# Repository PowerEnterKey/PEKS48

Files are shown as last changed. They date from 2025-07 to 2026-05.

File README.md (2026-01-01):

# PEKS48ビルドガイド
自作キーボードキットPEKS48のビルドガイドです。<br>
はんだ付け済み、ケース付き、ファームウェア書き込み済みですので、
ネジを締めて頂くだけでお使い頂けます。

## キット内容

| 名称 | 数  |　補足 |
| --- | --- | --- |
| メイン基板 | 2 |マイコンなど実装済み |
| トッププレート | 2 | |
| ケース(ボトム) | 1 | |
| ケース(トップ) | 1 | |
| Li-Poバッテリ | 2 | |
| ガスケット用フォーム |  -  |ケース及び基板の必要個所に取付済み |
| スイッチ取付面静音フォーム| 48 | |
| M2ネジ | 12 | |
| ゴム足 | 4 | |
| 給電ドッグ | 1 |無線給電機能付きの場合 |

※2025/12/31販売分まではスイッチ取付面静音フォームは取り付け済みで送付していましたが、<br>
　取り付け済みの状態だとスイッチの指す向きが分かりにくいことやフォーム自体がChoc V2適合品ではないことから<br>
　2025/12/31販売分から取り付けずに配布することにしました。<br>
　フォームを使用することで音は良くなるので取り付けを推奨しています。<br>
　取り付け向き等は以降の画像を参照ください。<br>
 
## キット以外に必要なもの

| 名称 | 数  |　補足 |
| --- | --- | --- |
| キースイッチ | 48  |choc v2互換　　|

## 組み立て手順
以下の状態で郵送されます（右手用）。<br>
キーキャップはただ置かれている状態です。<br>
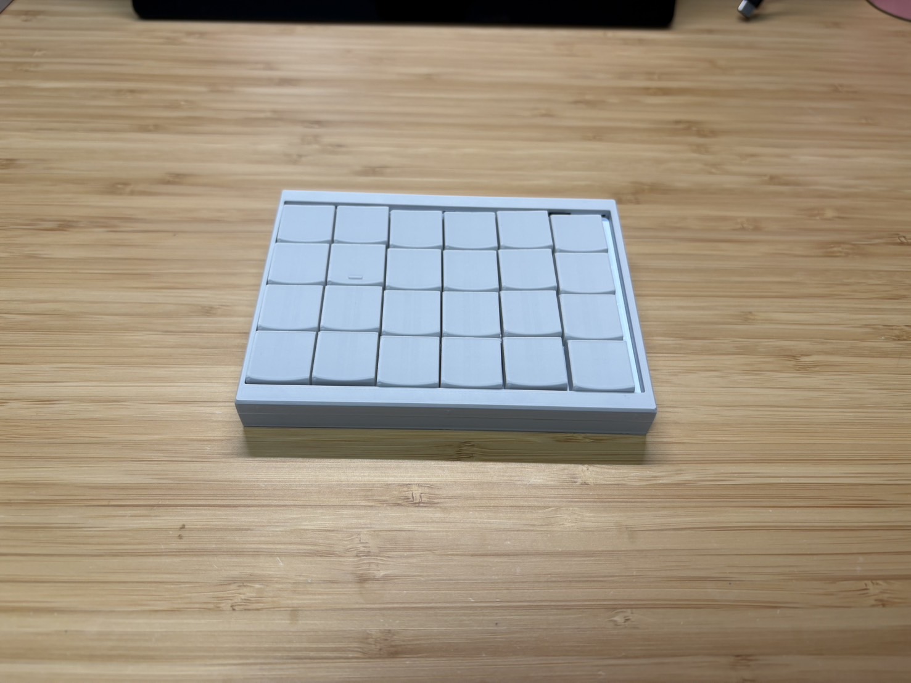
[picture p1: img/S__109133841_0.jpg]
<br>

キーキャップをとると右用か左用かが書かれています。<br>
PEKS48はハードウェアとしては右も左も完全に同じものです。ファームウェアのみ異なります。<br>
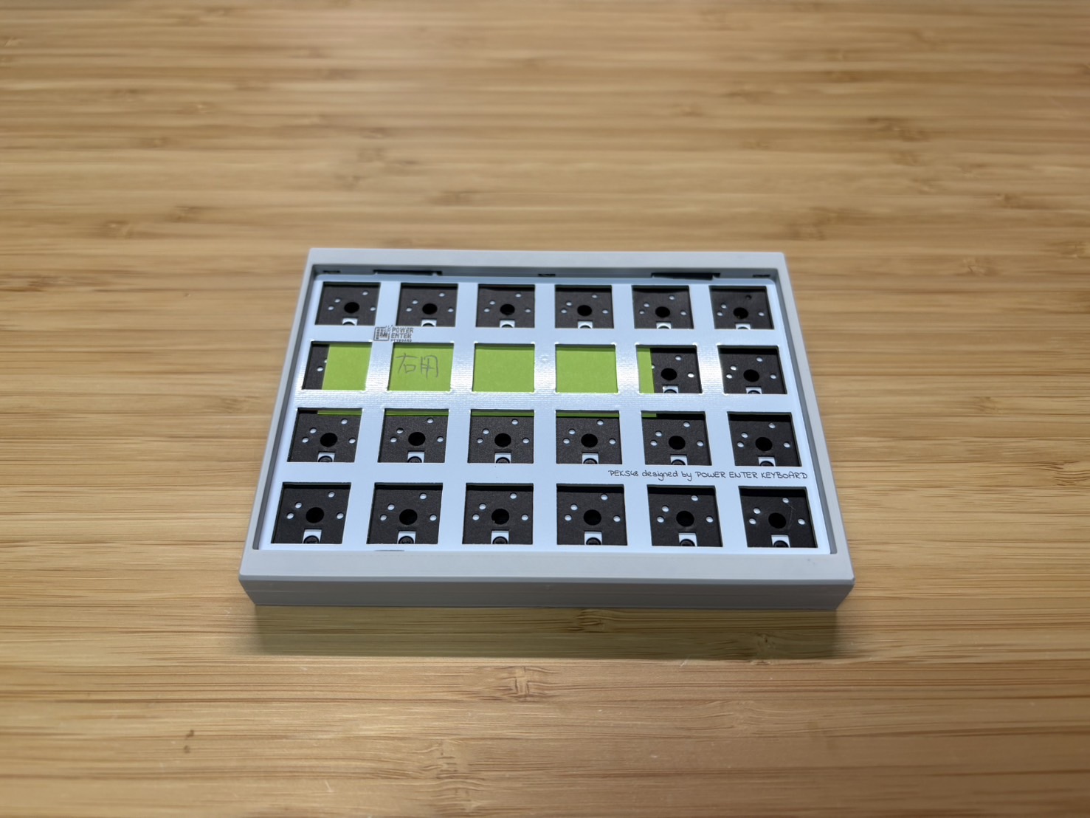
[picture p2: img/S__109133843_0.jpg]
<br>

裏返すと6か所にネジがあるので外します。<br>
(裏面には直径6mm厚さ2.5mmの磁石を入れることが出来る穴があるのでご自由に使用ください。<br>
　※2025/12/31販売分から磁石を入れる穴がケース内部になりました。外側から磁石が見えなくなってすっきりしました。)<br>
ネジを外すとケース(トップ) が外せます。<br>
右の図はケース(トップ) を外した状態です。<br>
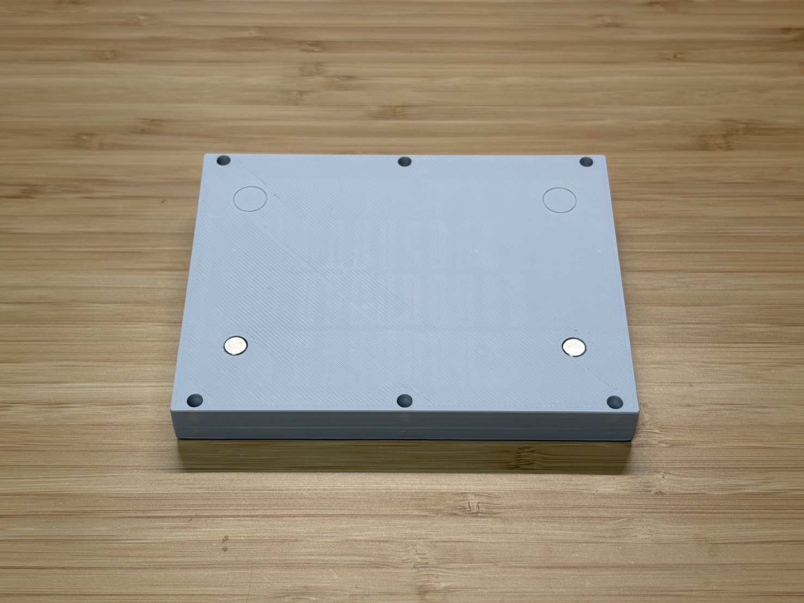
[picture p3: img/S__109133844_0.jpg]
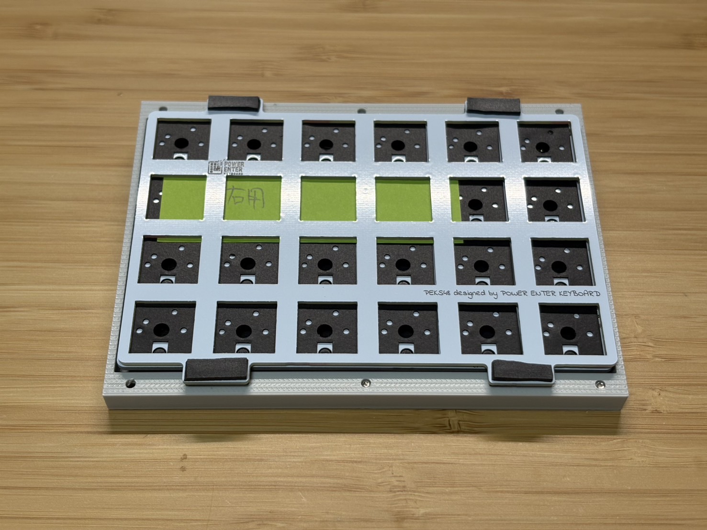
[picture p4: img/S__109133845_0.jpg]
<br>

次に、メイン基板の下側にバッテリが入っていますので、メイン基板と接続します。<br>
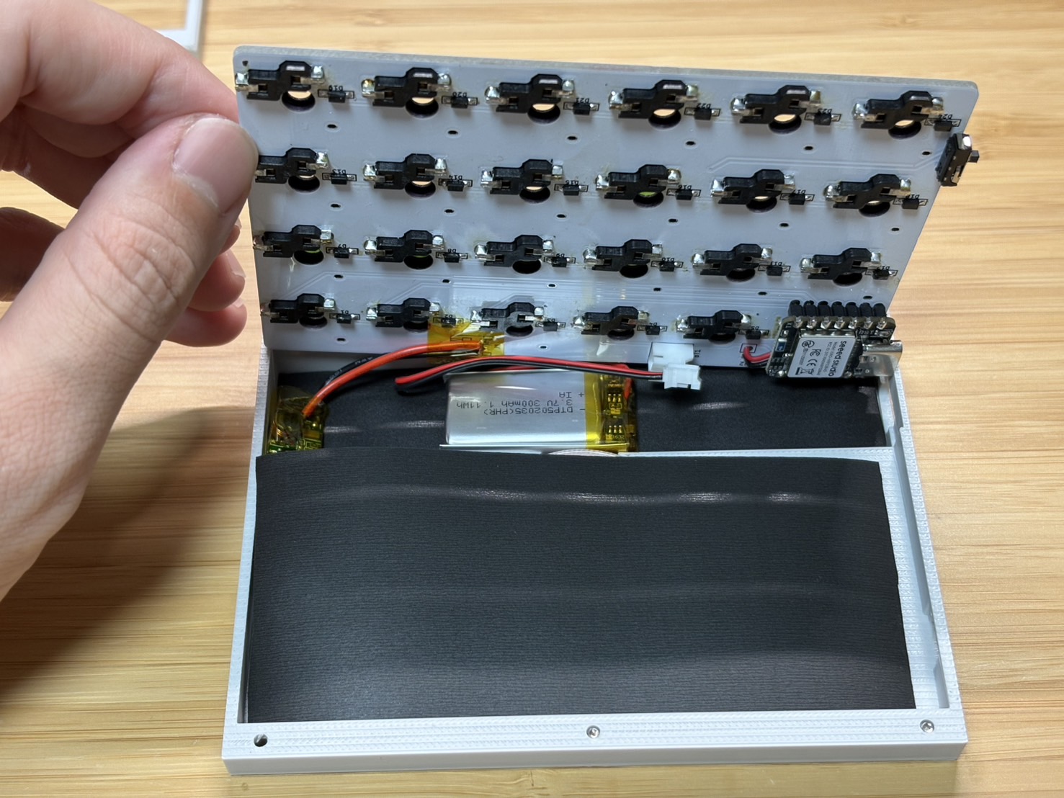
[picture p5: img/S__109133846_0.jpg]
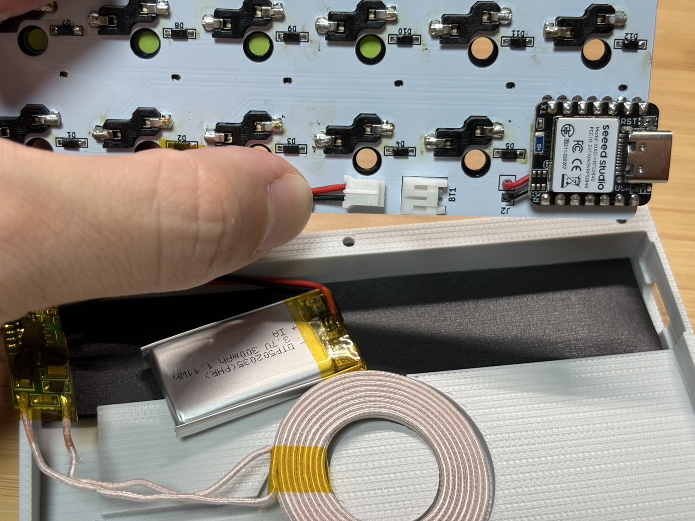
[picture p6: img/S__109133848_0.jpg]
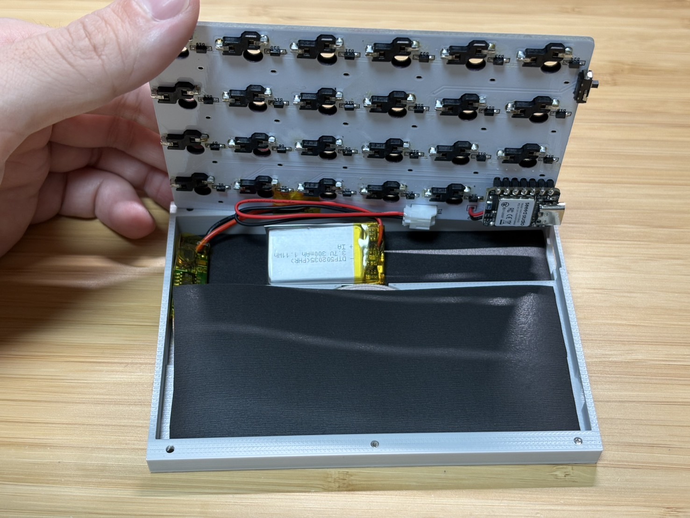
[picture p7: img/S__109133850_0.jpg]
<br>

バッテリがコネクタや無線給電用子基板と干渉しないように配置して、メイン基板をケースに収めます。<br>
※※その際、以下のようにケーブルをケースと基板の間に挟まないように注意してください。※※<br>
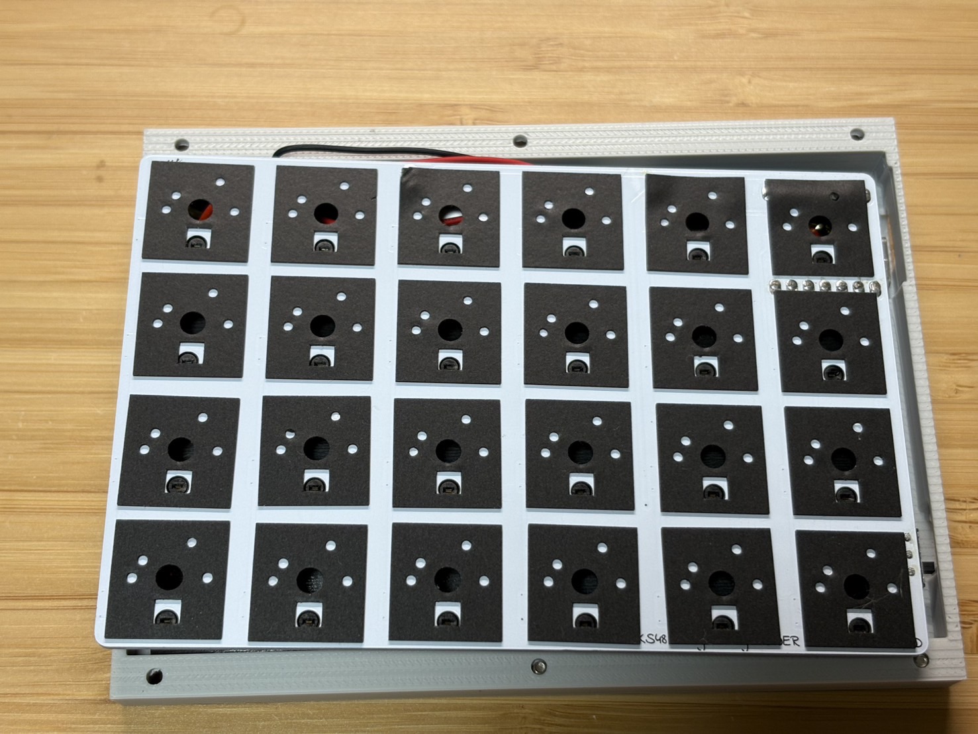
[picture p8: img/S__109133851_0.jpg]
<br>

次に、トッププレートにスイッチをはめていきます。<br>
スイッチはピンがある方が南側にくる向きではめてください。<br>
四隅をはめたらトッププレートごとスイッチを基板に挿します。<br>
そうする事で残りのキースイッチが挿しやすくなります。<br>
トッププレートはそこまで強度がないので注意して扱ってください。<br>
本キーボードは打鍵感向上の為にすでにスイッチ用フォームが基板に貼ってあります。<br>
(※2025/12/31販売分から取り付けずに配布。)<br>
Choc V2用のフォームではないですがこのまま挿して（フォームを貫通させて）問題ないです。<br>
この時点でキーキャップまではめてもよいです。<br>
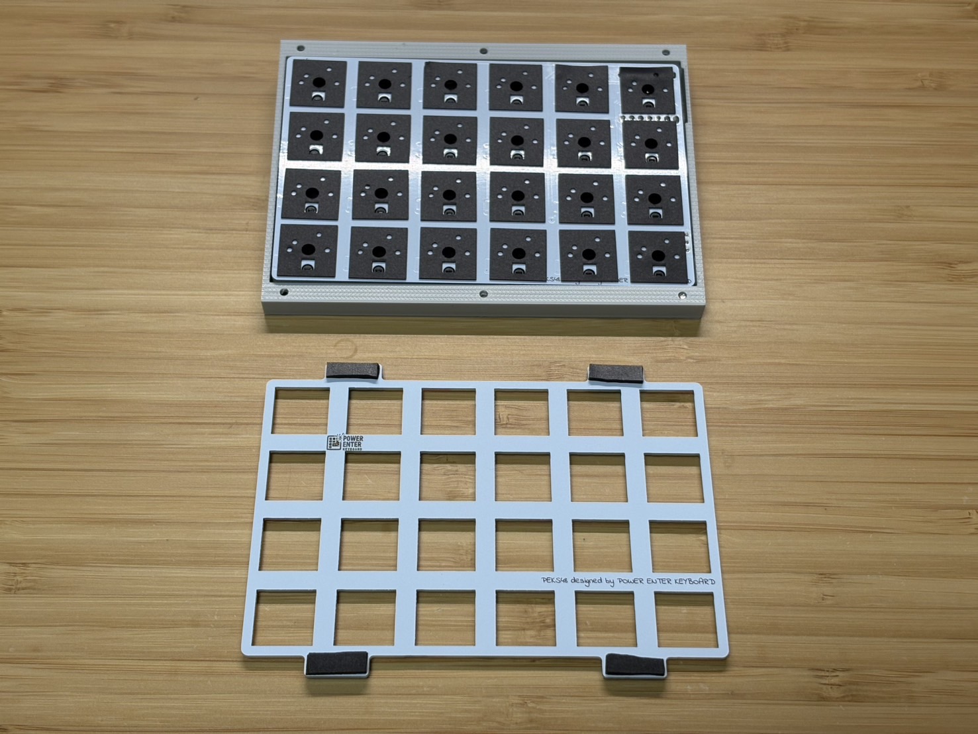
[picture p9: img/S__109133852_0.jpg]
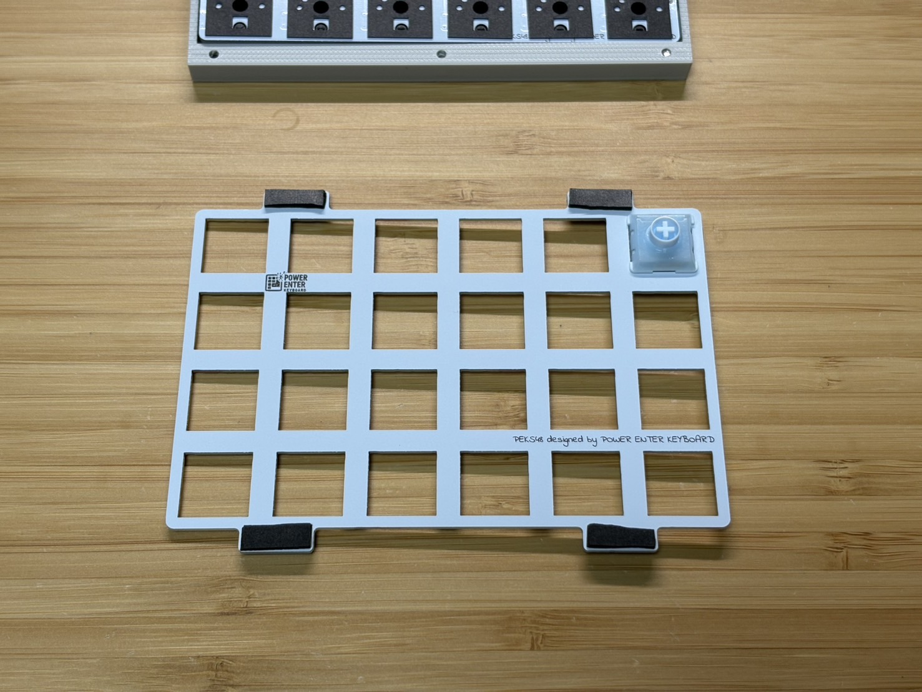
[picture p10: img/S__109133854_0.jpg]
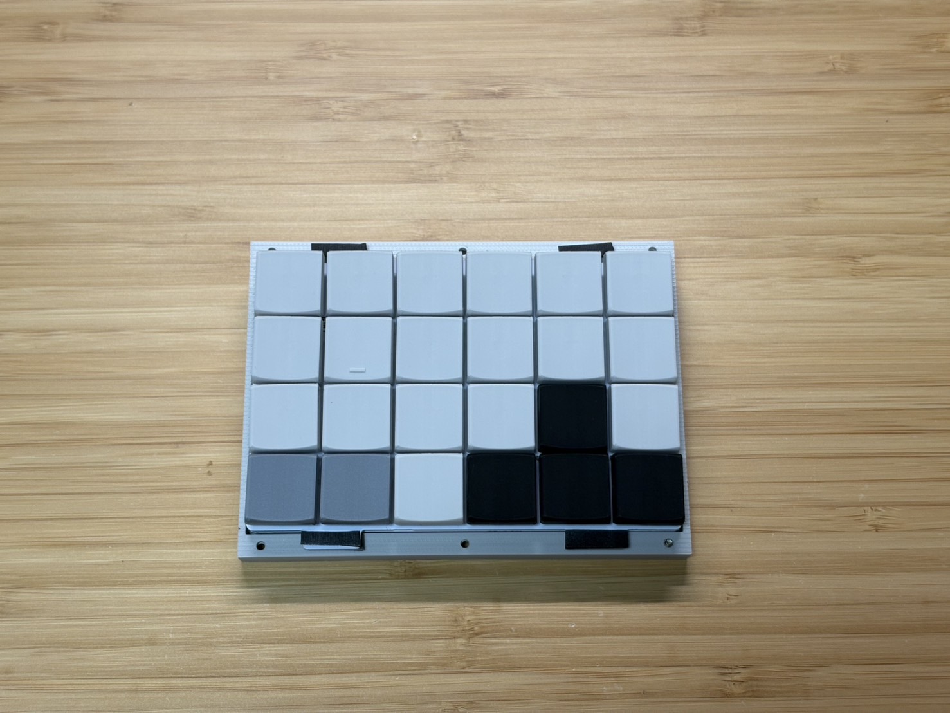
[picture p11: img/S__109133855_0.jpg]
<br>

ボトムケース、メイン基板＋トッププレート、トップケースの順に重ねてねじを締めます。<br>
トップケースにはインサートナットが埋め込まれています。<br>
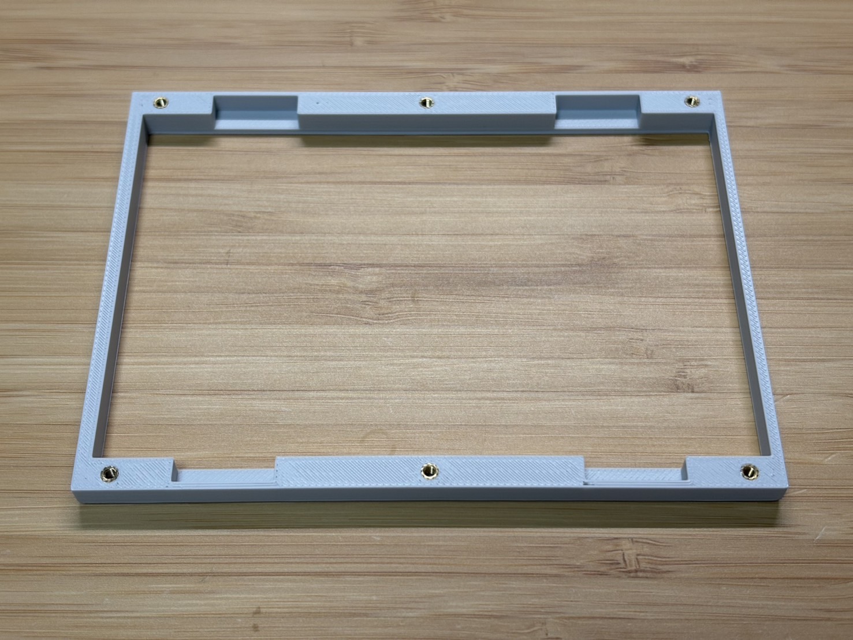
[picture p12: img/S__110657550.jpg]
<br>
また、ケース(トップ) は左右対称ではなく、右側が少し太くなっています。<br>
分かりにくいですが、若干太い方を右側にしてください。

最後に、ケース（トップ）を基板に被せて、開けた時のようにボトム側から6か所のネジを締めれば完成です。<br>
ケース裏面にゴム足を張る丸いマークがついています。ここに付属のゴム足をはると給電ドックとぴったりはまります。<br>
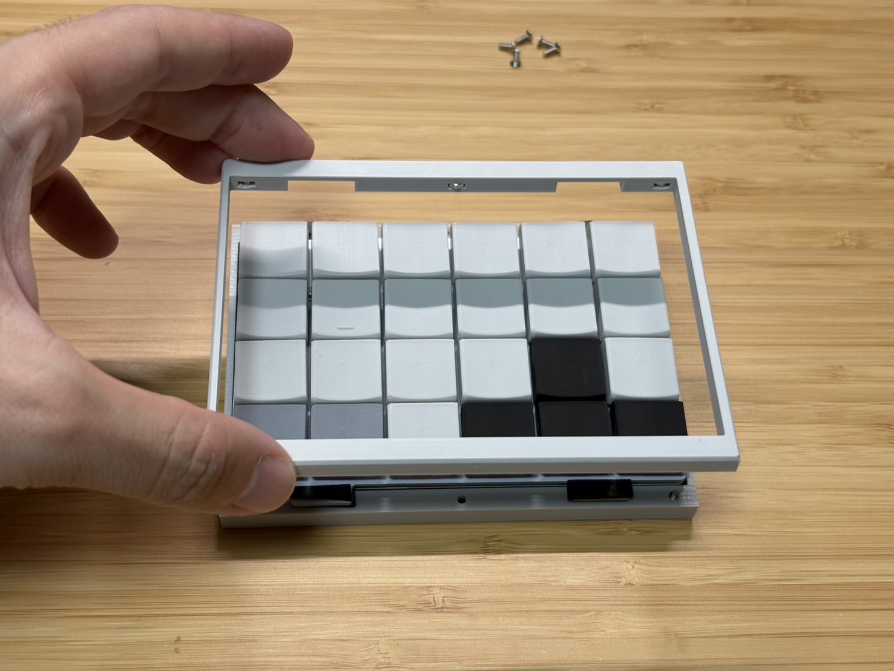
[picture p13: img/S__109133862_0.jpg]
<br>

※2025/12/31販売分から滑り止めがグリップラスという製品になりました。<br>
それに合わせてケース裏の目印も六角形になりました。<br>
上部2つのみに付けるとケースを重ねた時に滑り止め同士が干渉しにくいです。<br>
2つで滑り止め効果が弱いと感じる場合は目印通り4か所に付けてください。<br>
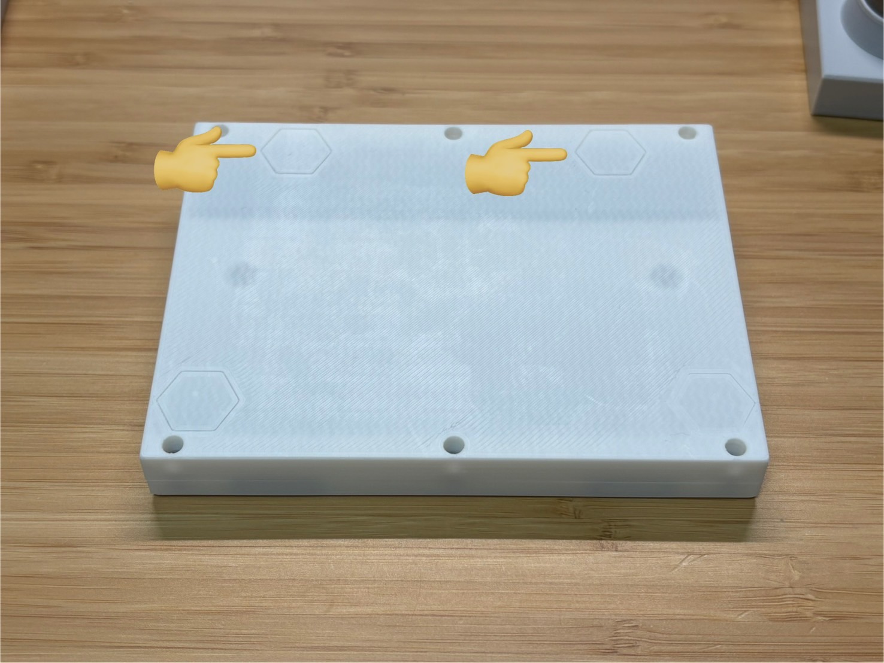
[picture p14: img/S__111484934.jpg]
<br>

完成です！！<br>
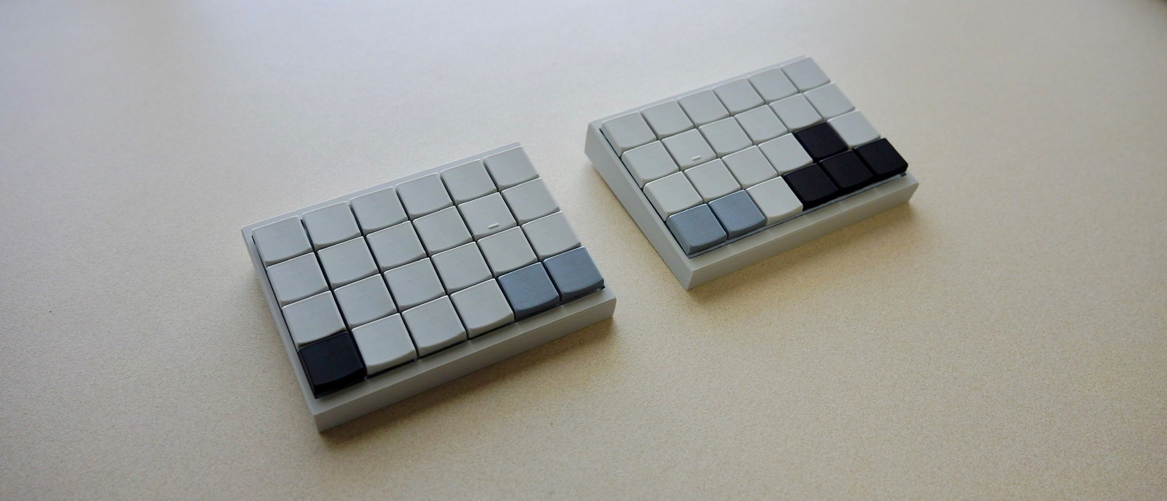
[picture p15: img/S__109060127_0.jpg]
<br>

## 無線給電について(※無線給電対応モデルのみ)
キーボードの裏にはマグネットが付いています。<br>
（下部3つのネジ穴の上にある2つの丸がマグネットが入る穴です）<br>
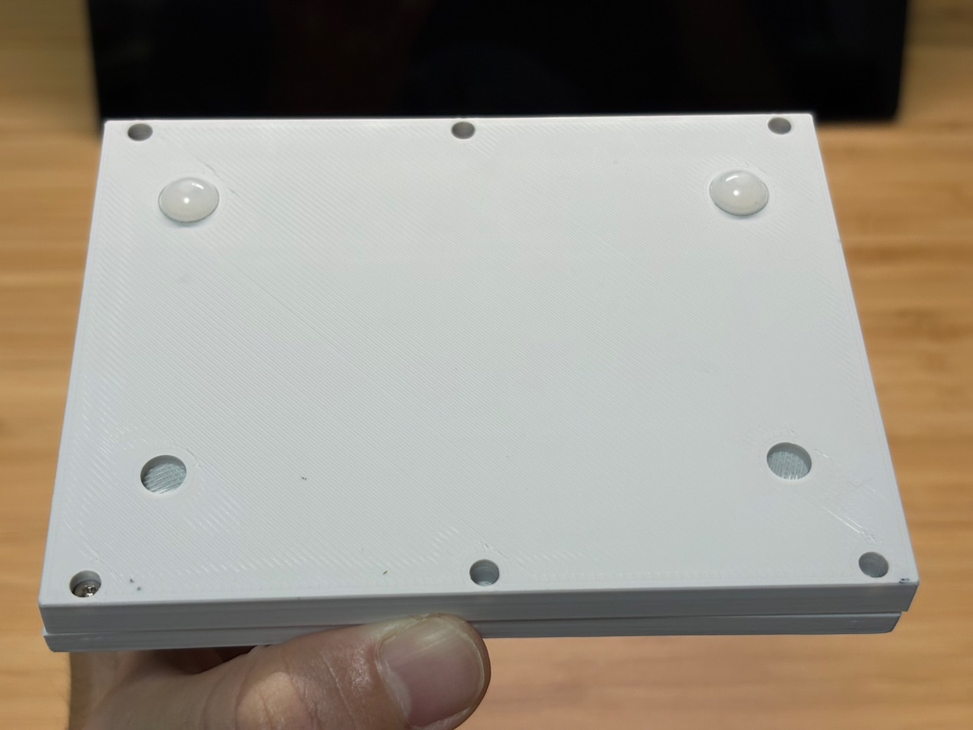
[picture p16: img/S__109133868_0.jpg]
<br>
無線給電したい際は、付属の無線給電ドッグのマグネットとキーボードのマグネットの位置を合わせると給電が始まります。<br>
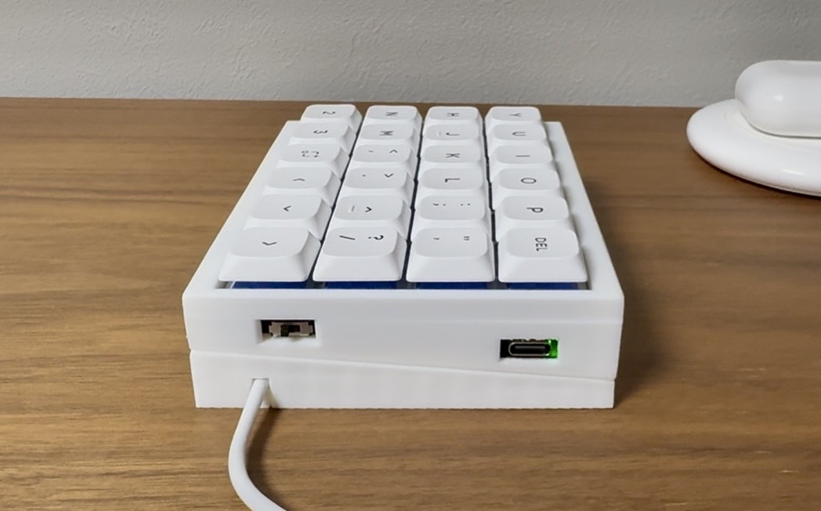
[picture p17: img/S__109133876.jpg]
<br>
PEKS48の無線給電機能は付属の給電ドックのみに対応しています。<br>
同様に付属の給電ドックはPEKS48のみに対応しています。<br>
対応しない機器での充電は避けてください。<br>

## 電源スイッチ
キーボード横に電源用スイッチがあります。（下記写真の左側の四角い穴）<br>
キーボードに向かって奥側（下記写真の右方向）が「ON」（バッテリからの給電許可）です。<br>
無線給電時はスイッチが「ON」でも「OFF」でも起動します。<br>
バッテリに充電したいときは「ON」にしてから給電ドックもしくはUSBを接続して充電してください。<br>
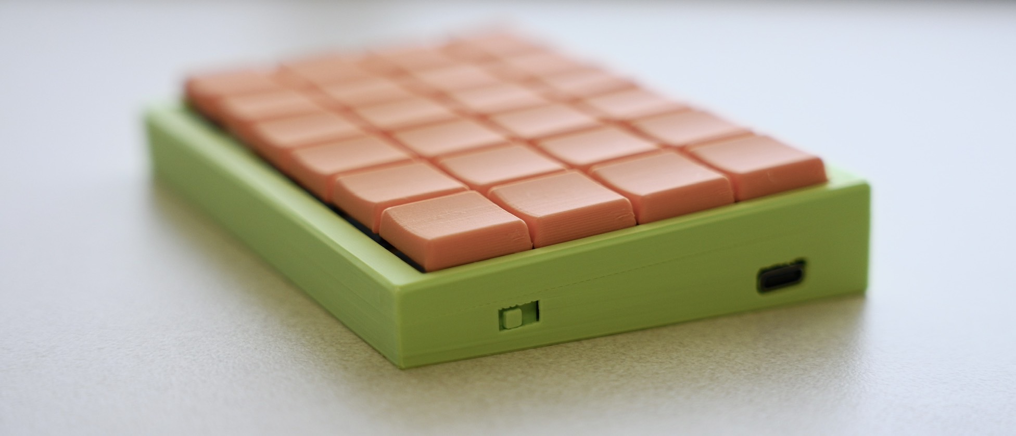
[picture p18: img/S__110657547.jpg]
<br>

## 初期キー配置
初期のキー配置は以下のようになっています。<br>
(日本語キーボードとして使用しているのでkeymap Editor上では一部エラーとして表示されてしまいます)<br>
詳細なキー配置は下記レポジトリのpeks48.keymapをご確認ください。<br>
[https://github.com/PowerEnterKey/zmk-PEKS48<br>](https://github.com/PowerEnterKey/zmk-PEKS48/blob/main/boards/shields/peks48/peks48.keymap)
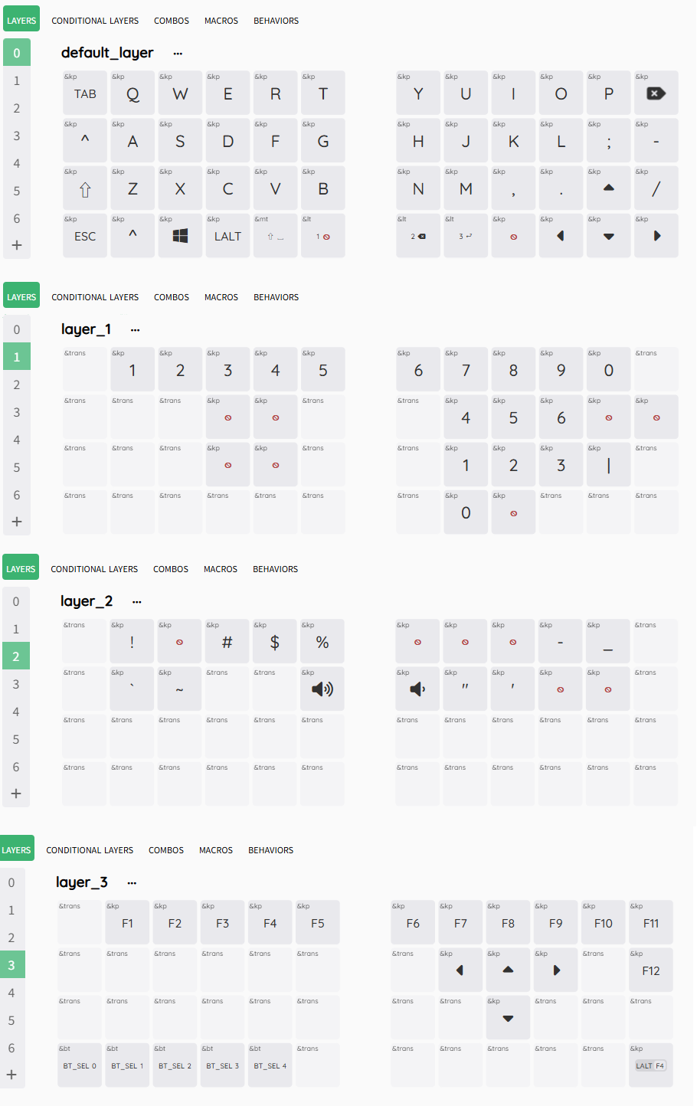
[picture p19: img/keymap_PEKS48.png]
<br>

PEKS48はKeymap Editorに対応しています。<br>
キーマップを変更したい場合は、
下記レポジトリをご自身のアカウントでフォークしてKeymap Editorにて変更をお願いします。<br>
https://github.com/PowerEnterKey/zmk-PEKS48<br>
ZMK StudioおよびKeymap Editorの詳しい使用方法につきましては、公開先のウェブサイトをご確認下さい。

## Bluetoothが繋がらない場合
PCとBluetoothのch選択が間違っている可能性があります。
Layer3にてBluetoothのchを変更してみてください。

それでもPCとBluetoothで接続できない場合は再度ファームウェアの書き込みを行ってください。<br>
右手用は下記の手順で実施します。<br>
・PCとPEKS48をUSBで接続します。<br>
・マイコン（XIAO BLE）のリセットボタンを2回連続で押すと、「XIAO SENSE」という名前でUSBドライブとして認識されます。<br>
・本レポジトリ内にある「settings_reset-seeeduino_xiao_ble-zmk.uf2」を「XIAO SENSE」にドラック&ドロップします。<br>
　書込みが完了すると「XIAO SENSE」ドライブは消えます。<br>
・再度リセットボタンを2回連続で押して、本レポジトリ内の「peks48_r rgbled_adapter-seeeduino_xiao_ble-zmk.uf2」にドラック&ドロップします。<br>

左手用は上記手順で最後に「peks48_l rgbled_adapter-seeeduino_xiao_ble-zmk.uf2」を書きます。<br>

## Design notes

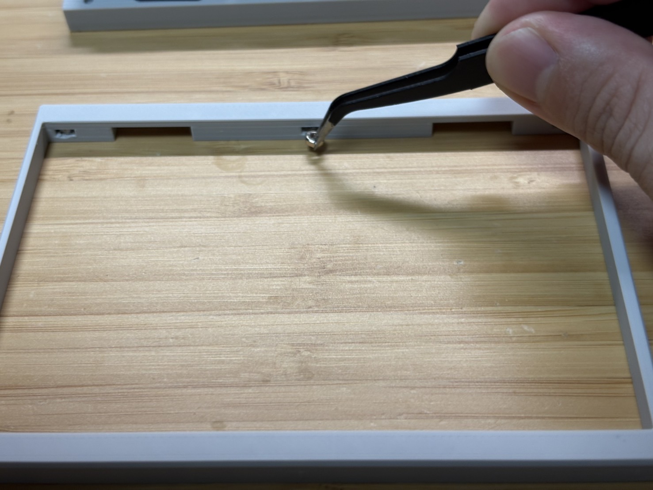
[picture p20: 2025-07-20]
img/S__109133858_0.jpg

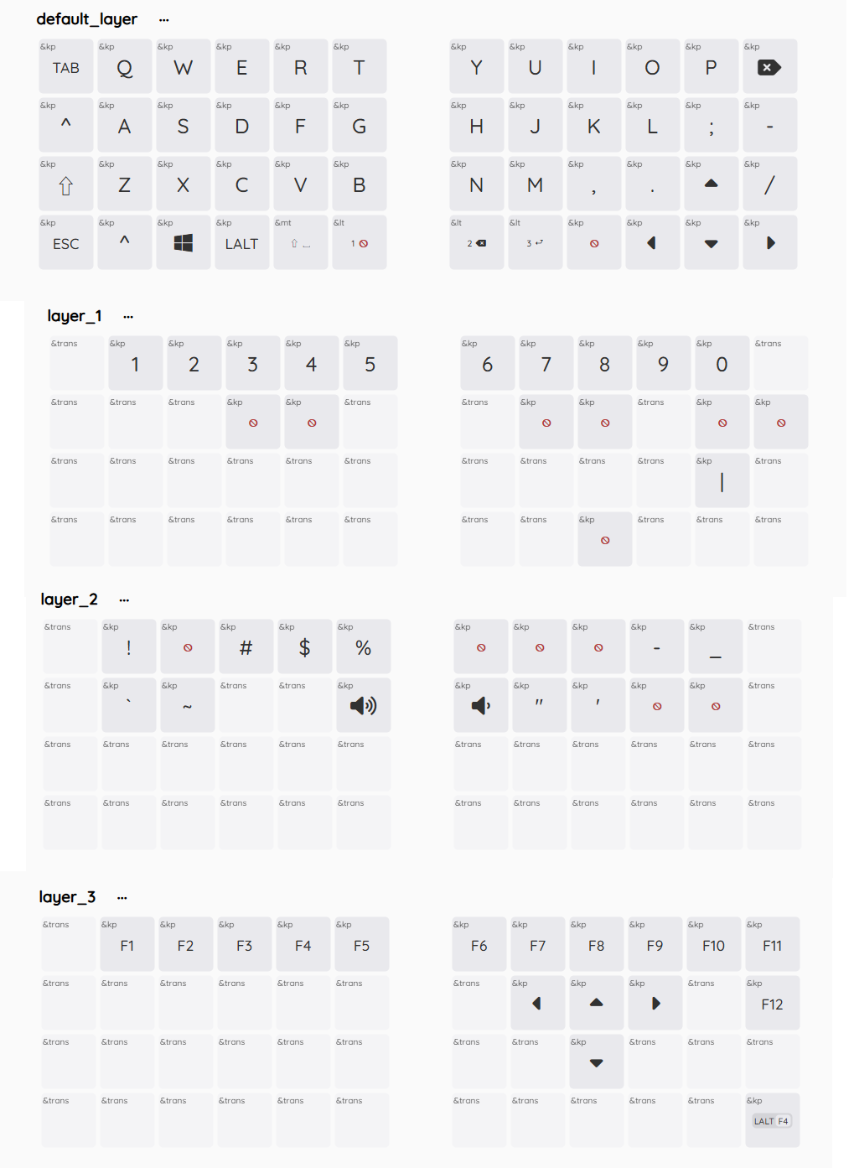
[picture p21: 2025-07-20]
img/keymap.png

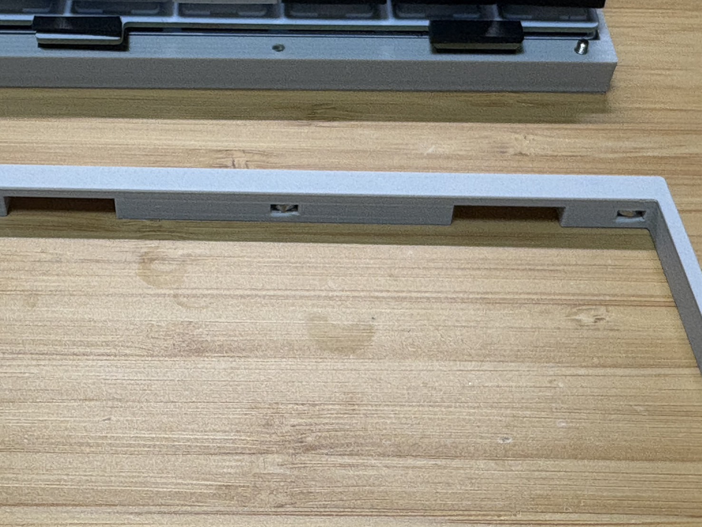
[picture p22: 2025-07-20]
img/S__109133860_0.jpg

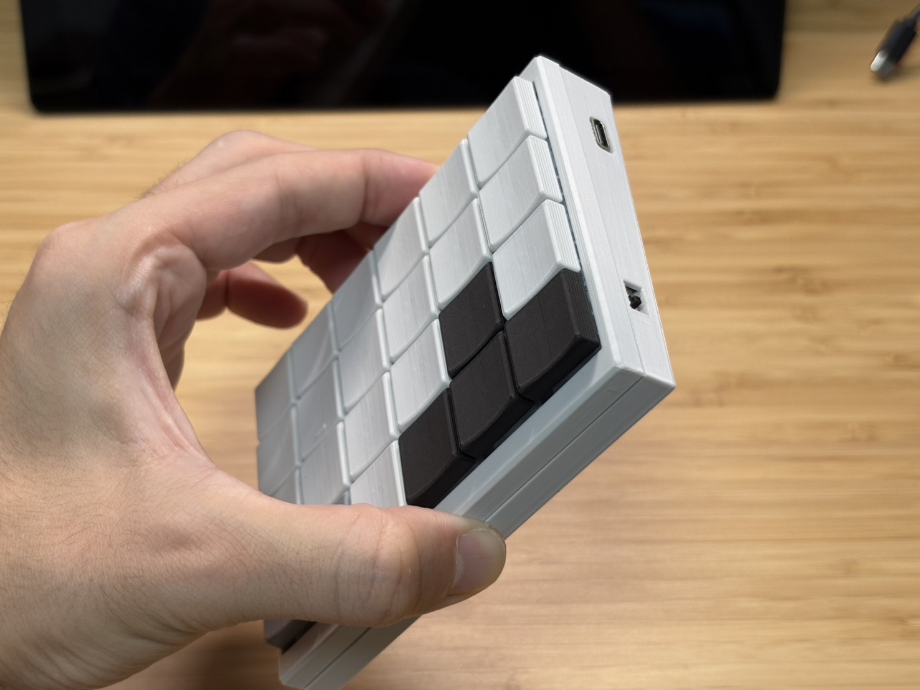
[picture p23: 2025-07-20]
img/S__109133865_0.jpg

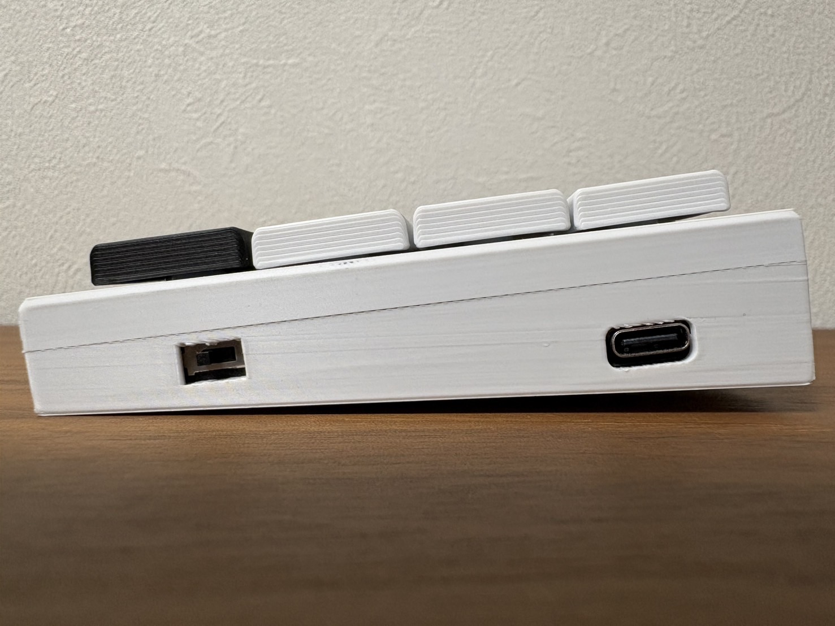
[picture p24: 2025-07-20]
img/S__109133877.jpg

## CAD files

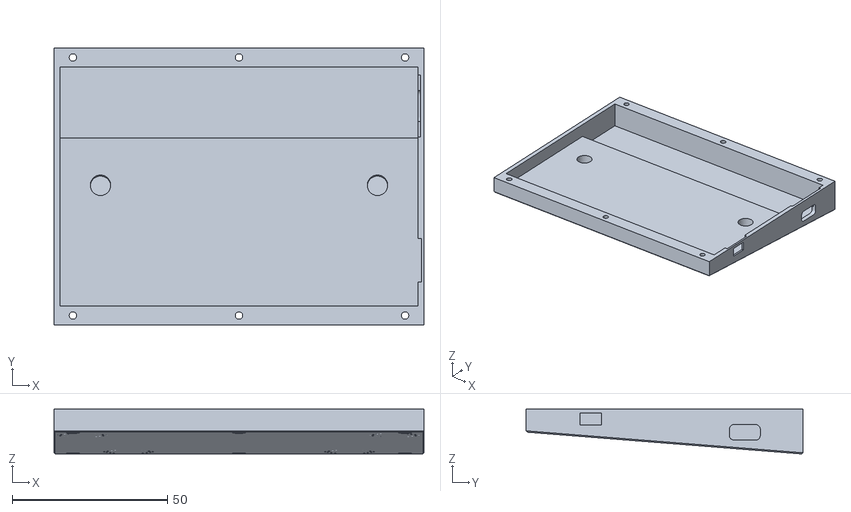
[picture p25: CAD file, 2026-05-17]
case/bottom_v3.stl
119.3 x 89.2 x 14.5

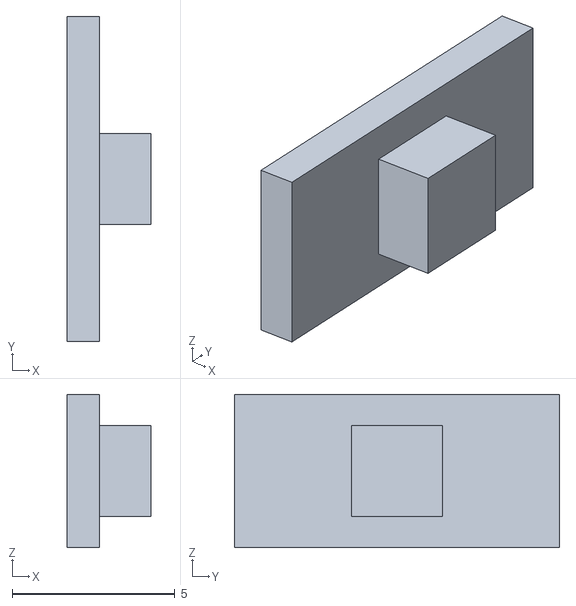
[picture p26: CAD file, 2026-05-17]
case/slide-sw_v8.stl
2.60 x 10.00 x 4.71

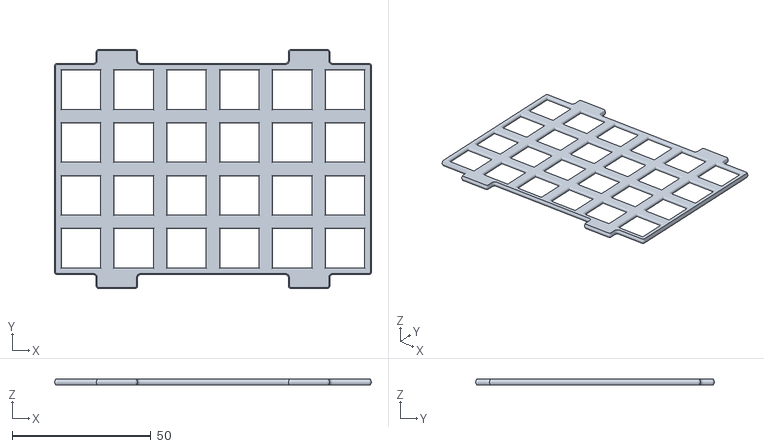
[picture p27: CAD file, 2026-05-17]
case/topplate_v7.stl
114.3 x 86.2 x 2.20

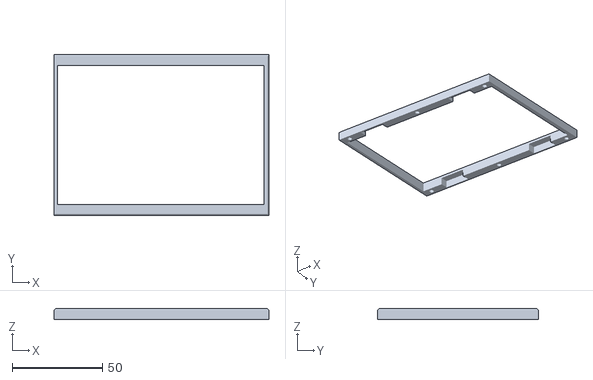
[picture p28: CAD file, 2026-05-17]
case/top_v11.stl
119.3 x 89.2 x 6.00

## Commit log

2025-11-17 README.md を更新
2026-01-01 Revise README with installation and assembly details
    Updated instructions regarding the silent foam for switch installation and clarified the handling of magnets in the case. Added notes on the assembly process and changes effective from 2025/12/31.
